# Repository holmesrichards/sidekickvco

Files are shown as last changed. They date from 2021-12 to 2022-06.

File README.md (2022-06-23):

# Sidekick VCO

The Sidekick VCO is a 3340 based voltage controlled oscillator synth module in Kosmo format. Notable features of the Sidekick include:

* Triangle, ramp, pulse, and sine waveforms with separate output jacks.
* Uniform, zero-centered ±5 Vpp output amplitudes for the various wave shapes.
* Input jacks for V/oct, PWM, and linear FM CV.
* Wide pulse width range.
* Switch selectable hard, soft, or no sync.
* 5 position octave switch plus fine tuning knob.
* Front panel access to trimmers for calibration of V/oct tracking, center pitch, and pulse width range limit.
* Entirely through hole construction with readily available components.

Two well known problems with the 3340 in its datasheet configuration are addressed:

* Regulated -5 V supply improves stability and suppresses pulse width frequency shift.
* Falling edge oscillations on pulse wave shape are eliminated.

But perhaps the most significant feature of the design is the link header. This may be used to connect the Sidekick's sister module, the [Hero VCO](https://github.com/holmesrichards/herovco), to one or more Sidekicks, in a modern riff on the classic Moog 921a/921b system. The Sidekick is half the width of the Hero and lacks some of the Hero's front panel controls and inputs, but internally is essentially the same circuit as the Hero. Via the link, the Sidekicks receive summed V/oct pitch CV, linear FM CV, and pulse width CV from the Hero, based on its front panel controls and inputs. In this way a common set of control voltages is presented to the Hero and all its Sidekicks. The link also permits the Sidekicks to be hard or soft synced to the Hero. This allows easy configuration of a multi-oscillator synth voice in a relatively compact system.

The Sidekick design specifies and assumes the Alfa AS3340A VCO chip, an improvement to the AS3340, although the AS3340 or Curtis CEM3340 probably would work. (See build notes.)

Thanks for inspiration to several other VCOs: the [Kassutronics VCO 3340](https://kassu2000.blogspot.com/2018/06/vco-3340.html), the [LMNC 1222 Performance VCO](https://www.lookmumnocomputer.com/1222-performance-vco), and the [Thomas Henry VCO Maximus](https://www.birthofasynth.com/Thomas_Henry/Pages/VCO_Maximus-Detail.html).

## Project status

One prototype has been built and it works. There were some very minor issues with the PCB which have been corrected in the design files but the revised version has not been built.

## Width

5 cm.

## Current draw
? mA +12 V, ? mA -12 V.

## Photos

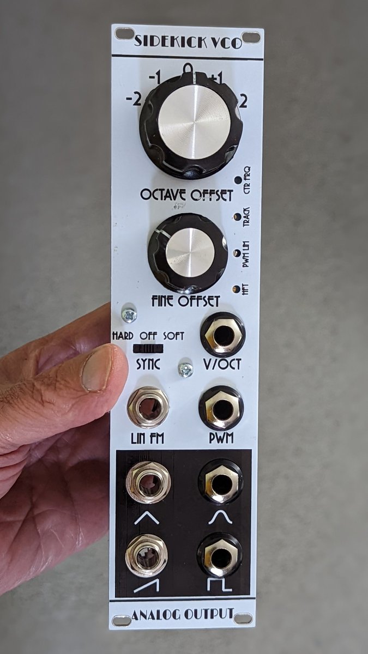
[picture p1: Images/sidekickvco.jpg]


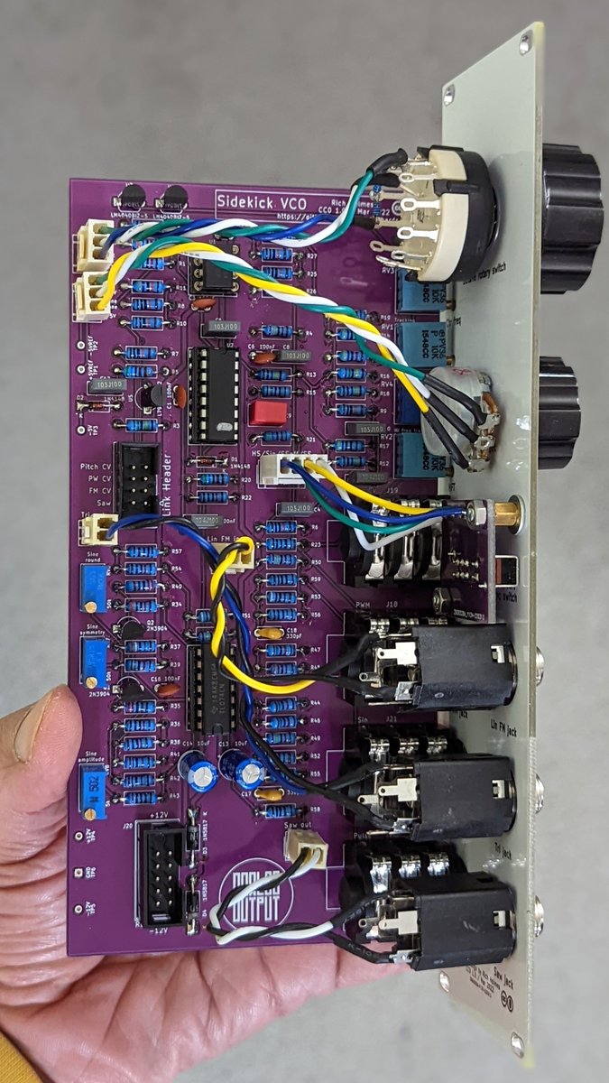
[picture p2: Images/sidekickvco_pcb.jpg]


## Documentation

* [Schematic](Docs/sidekickvco.pdf)
* PCB layout: [front](Docs/sidekickvco_layout_front.pdf), [back](Docs/sidekickvco_layout_back.pdf)
* [BOM](Docs/sidekickvco_bom.md)
* [Build notes](Docs/build.md)
* [How it works](Docs/howitworks.md)
* [Blog post](https://analogoutputblog.wordpress.com/2022/06/20/hero-and-sidekick/)

## GitHub repository

* [https://github.com/holmesrichards/sidekickvco](https://github.com/holmesrichards/sidekickvco)

## Submodules

This repo uses submodules aoKicad and Kosmo_panel, which provide needed libaries for KiCad. To clone:

```
git clone git@github.com:holmesrichards/sidekickvco.git
git submodule init
git submodule update
```

Alternatively do

```
git clone --recurse-submodules git@github.com:holmesrichards/sidekickvco.git
```

Or if you download the repository as a zip file, you must also click on the "aoKicad" and "Kosmo\_panel" links on the GitHub page (they'll have "@ something" after them) and download them as separate zip files which you can unzip into this repo's aoKicad and Kosmo\_panel directories.

If desired, copy the files from aoKicad and Kosmo\_panel to wherever you prefer (your KiCad user library directory, for instance, if you have one). Then in KiCad, go into Edit Symbols and add symbol libraries 

```
aoKicad/ao_symbols
Kosmo_panel/Kosmo
```
and go into Edit Footprints and add footprint libraries 
```
aoKicad/ao_tht
Kosmo_panel/Kosmo_panel.
```

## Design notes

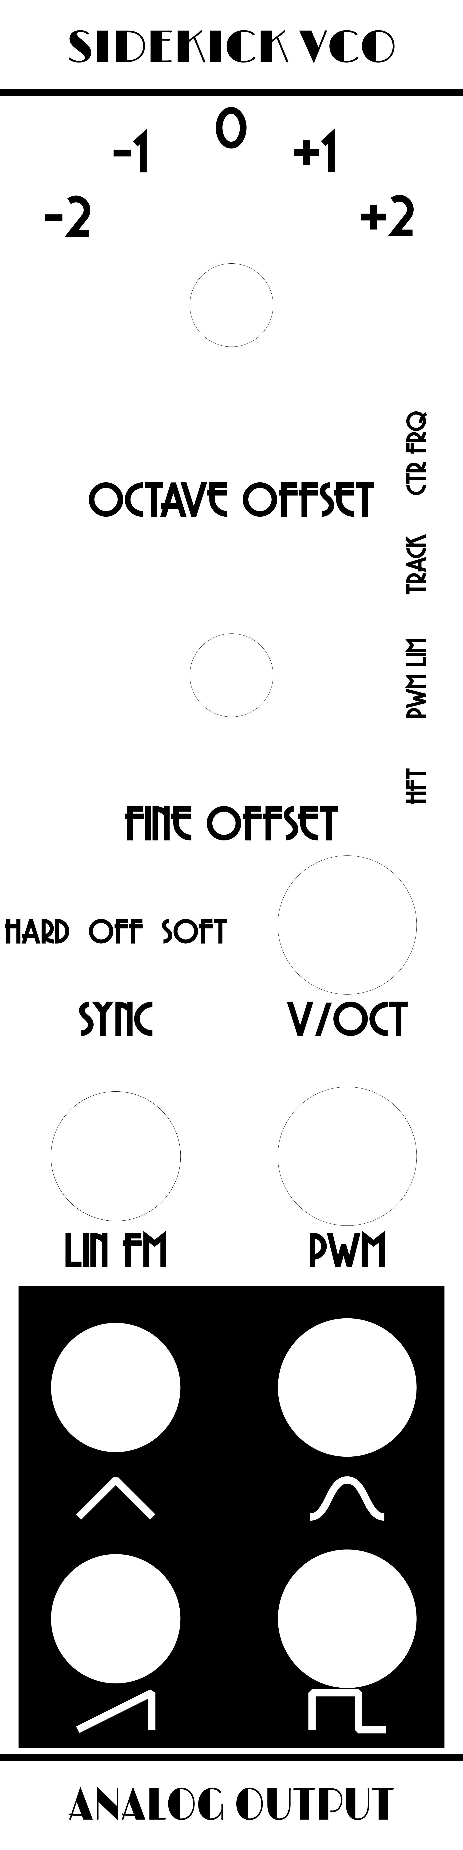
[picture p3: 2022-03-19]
Images/sidekick_panel_art.png

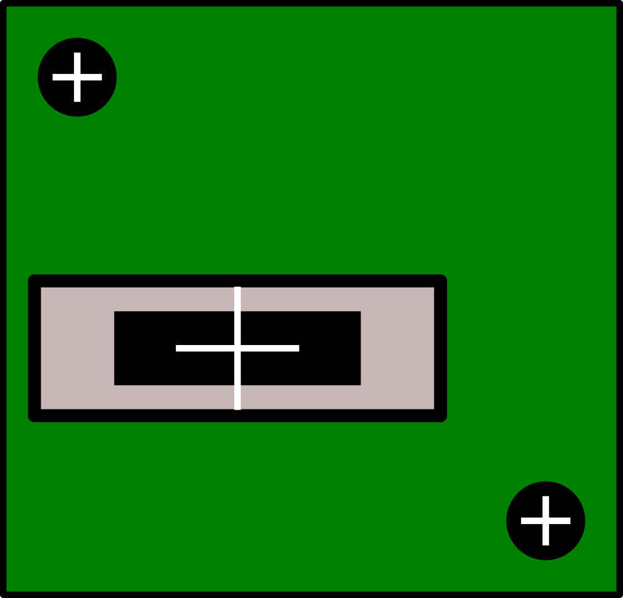
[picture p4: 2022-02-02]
Images/sidekick_daughterboard.png

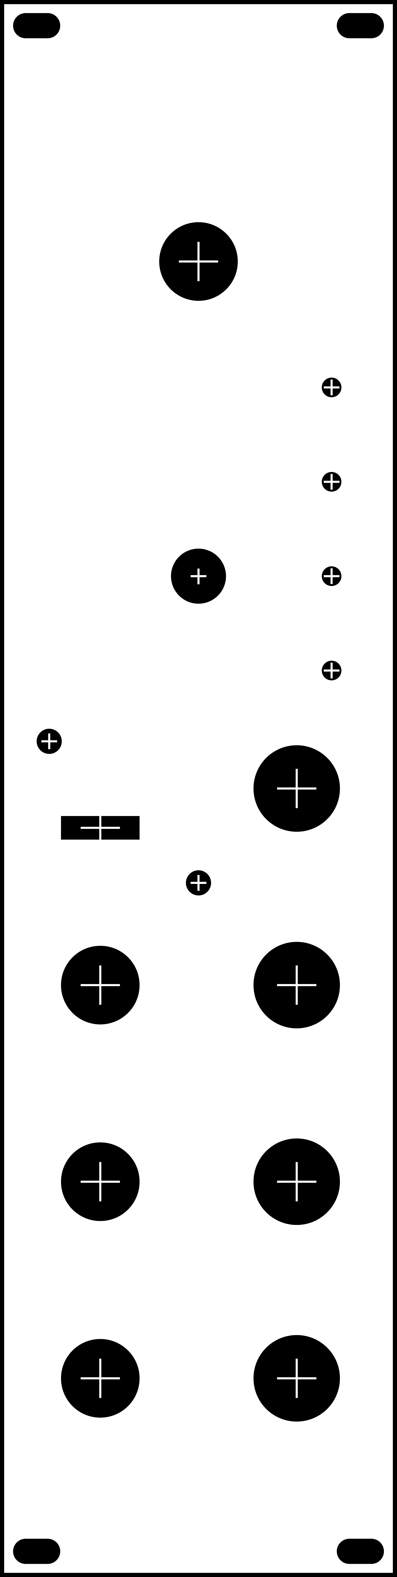
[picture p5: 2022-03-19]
Images/sidekick_panel_holes.png

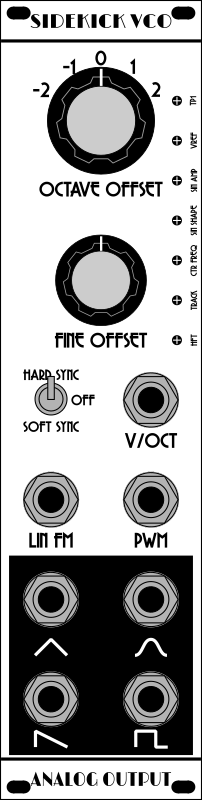
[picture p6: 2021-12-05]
Images/sidekick_panel.png

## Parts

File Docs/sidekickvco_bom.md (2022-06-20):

# sidekickvco.kicad_sch BOM

Sun 19 Jun 2022 12:23:22 PM EDT

Generated from schematic by Eeschema 6.0.5-a6ca702e91~116~ubuntu20.04.1

**Component Count:** 120

| Refs | Qty | Component | Description | Manufacturer | Part | Vendor | SKU |
| ----- | --- | ---- | --- | ---- | ---- | ---- | ---- |
| C1, C2, C3, C6, C15, C16 | 6 | 100nF | Ceramic capacitor, pitch 2.5 mm |  |  | Tayda |  |
| C4, C5, C8, C10, C12 | 5 | 10nF | Film capacitor, pitch 5 mm |  |  | Tayda | A-559 |
| C7, C11 | 2 | 100nF | Film capacitor, pitch 5 mm |  |  | Tayda | A-564 |
| C9 | 1 | 1nF | Polypropylene film capacitor |  |  | Digi-Key | FKP2G011001D00HSSD |
| C13, C14 | 2 | 10uF | Electrolytic capacitor, pitch 2.5 mm |  |  | Tayda |  |
| C17, C18 | 2 | 330pF | Ceramic capacitor, pitch 5 mm |  |  | Tayda |  |
| D1, D2 | 2 | 1N4148 | Standard switching diode, DO-35 |  |  | Tayda | A-157 |
| D3, D4 | 2 | 1N5817 | Schottky Barrier Rectifier Diode, DO-41 |  |  | Tayda | A-159 |
| J1 | 1 | Conn_02x04_Odd_Even | 2x4 shrouded pin header, pitch 2.54 mm |  |  | Tayda | A-2948 |
| J2, J3 | 2 | 3_pin_Molex_header | KK254 Molex header |  |  | Tayda | A-805 |
| J4 | 1 | 4_pin_Molex_header | KK254 Molex header |  |  | Tayda | A-806 |
| J5, J6, J7 | 3 | 2_pin_Molex_header | KK254 Molex header |  |  | Tayda | A-804 |
| J8, J9 | 2 | 3_pin_Molex_connector | KK254 Molex connector |  |  | Tayda | A-827 |
| J10 | 1 | 4_pin_Molex_connector | KK254 Molex connector |  |  | Tayda | A-828 |
| J11, J12, J13 | 3 | 2_pin_Molex_connector | KK254 Molex connector |  |  | Tayda | A-826 |
| J18, J19, J21, J22 | 4 | AudioJack2 | 1/4" audio jack, horizontal |  |  | Tayda | A-1122 |
| J20 | 1 | Synth_power_2x5 | 2x5 shrouded pin header, pitch 2.54 mm |  |  | Tayda | A-2939 |
| J23, J24, J25 | 3 | AudioJack2 | 1/4" audio jack, vertical |  |  | Tayda | A-1121 |
| Q1, Q2 | 2 | 2N3904 | Small Signal NPN Transistor, TO-92 |  |  | Tayda | A-111 |
| R1, R2, R34 | 3 | 30k | Resistor |  |  | Tayda |  |
| R3, R12, R13, R18 | 4 | 1M | Resistor |  |  | Tayda |  |
| R4, R48, R49, R50 | 4 | 24k | Resistor |  |  | Tayda |  |
| R5, R20 | 2 | 5.6k | Resistor |  |  | Tayda |  |
| R6, R7, R8, R9, R10, R25, R26, R27 | 8 | 100k | Resistor |  |  | Tayda |  |
| R11 | 1 | 470k | Resistor |  |  | Tayda |  |
| R14, R17 | 2 | 470R | Resistor |  |  | Tayda |  |
| R15 | 1 | 1.8k | Resistor |  |  | Tayda |  |
| R16 | 1 | 1.5M | Resistor |  |  | Tayda |  |
| R19, R21, R28 | 3 | 47k | Resistor |  |  | Tayda |  |
| R22, R36, R38, R54, R55, R56 | 6 | 10k | Resistor |  |  | Tayda |  |
| R23, R24, R57, R58, R59 | 5 | 1k | Resistor |  |  | Tayda |  |
| R29, R41, R42 | 3 | 20k | Resistor |  |  | Tayda |  |
| R30, R31, R32, R33 | 4 | 10k 1/8W | Resistor |  |  | Tayda |  |
| R35, R40 | 2 | 2.2k | Resistor |  |  | Tayda |  |
| R37 | 1 | 390R | Resistor |  |  | Tayda |  |
| R39, R44, R46, R47 | 4 | 18k | Resistor |  |  | Tayda |  |
| R43 | 1 | 2k | Resistor |  |  | Tayda |  |
| R45 | 1 | 33k | Resistor |  |  | Tayda |  |
| R51, R52, R53 | 3 | 9.1k | Resistor |  |  | Tayda |  |
| RV1, RV2, RV3 | 3 | 10k | 3296P trimmer potentiometer |  |  | Digi-Key | CT94EP103-ND |
| RV4 | 1 | 50k | 3296P trimmer potentiometer |  |  | Digi-Key | CT94EP503-ND |
| RV5 | 1 | 100k | Panel mount linear potentiometer |  |  | Tayda | A-5606 or A-1984 |
| RV6, RV7 | 2 | 50k | 3296W trimmer potentiometer |  |  | Tayda | A-598 |
| RV8 | 1 | 5k | 3296W trimmer potentiometer |  |  | Tayda | A-597 |
| SW1 | 1 | SW_Rotary12 | rotary switch with 12 positions |  |  | Tayda | A-1893 |
| SW2 | 1 | SW_DP3T | Switch, three position, dual pole triple throw, 3 position switch, SP3T | C&K | OS203012MU5QP1‎ | Digi-Key | CKN9554-ND |
| U1 | 1 | TL072 | Dual operational amplifier, DIP-8 |  |  | Tayda | A-037 |
| U2 | 1 | AS3340A | VCO |  |  | CabinTech Global |  |
| U3, U4 | 2 | LM4040BIZ-5 | 5.000V Precision Micropower Shunt Voltage Reference, TO-92 |  |  | Digi-Key | LM4040BIZ-5/NOPB-ND |
| U5 | 1 | L79L05_TO92 | Negative 100mA -30V Linear Regulator, Fixed Output -5V, TO-92 |  |  | Tayda | A-4676 |
| U6 | 1 | TL074 | Quad operational amplifier, DIP-14 |  |  | Tayda | A-1138 |
| | 2 or more* | | 8 pin IDC connector | | | Tayda | A-3346 |
| | Length as needed | | 8 conductor ribbon cable | | | Tayda | A-4935 |
| | 2 | | Knob | | | | |
| | 1 | | 8 pin DIP socket | | | Tayda | A-001 |
| | 1 | | 14 pin DIP socket | | | Tayda | A-004 |
| | 1 | | 16 pin DIP socket | | | Tayda | A-003 |
| | 2 | | M3x12 screw | | | | |
| | 2 | | 5 mm spacer | | | Tayda | A-1235 |
| | 2 | | M3 nut | | | | |
    
\* One connector for Hero and one for each Sidekick connecting to it

## Caveat emptor

Bourns 3296P 10k trimmers are specified for the panel accessible trimmers. Bourns PV36 trimmers seem to have the same specs and dimensions, as do Nidec Copal CT94E trimmers. Any of these should work. Similar trimmers from other manufacturers *may* differ slightly in their dimensions which may cause misalignment between panel and PCB. Compare datasheets carefully before buying.

The jacks are from Tayda, SKU A-1122 or A-3617 (seemingly identical). This appears to be the same as jacks sold under the model number PJ-644C elsewhere. Again, similar looking jacks from other sources may have slightly different dimensions.

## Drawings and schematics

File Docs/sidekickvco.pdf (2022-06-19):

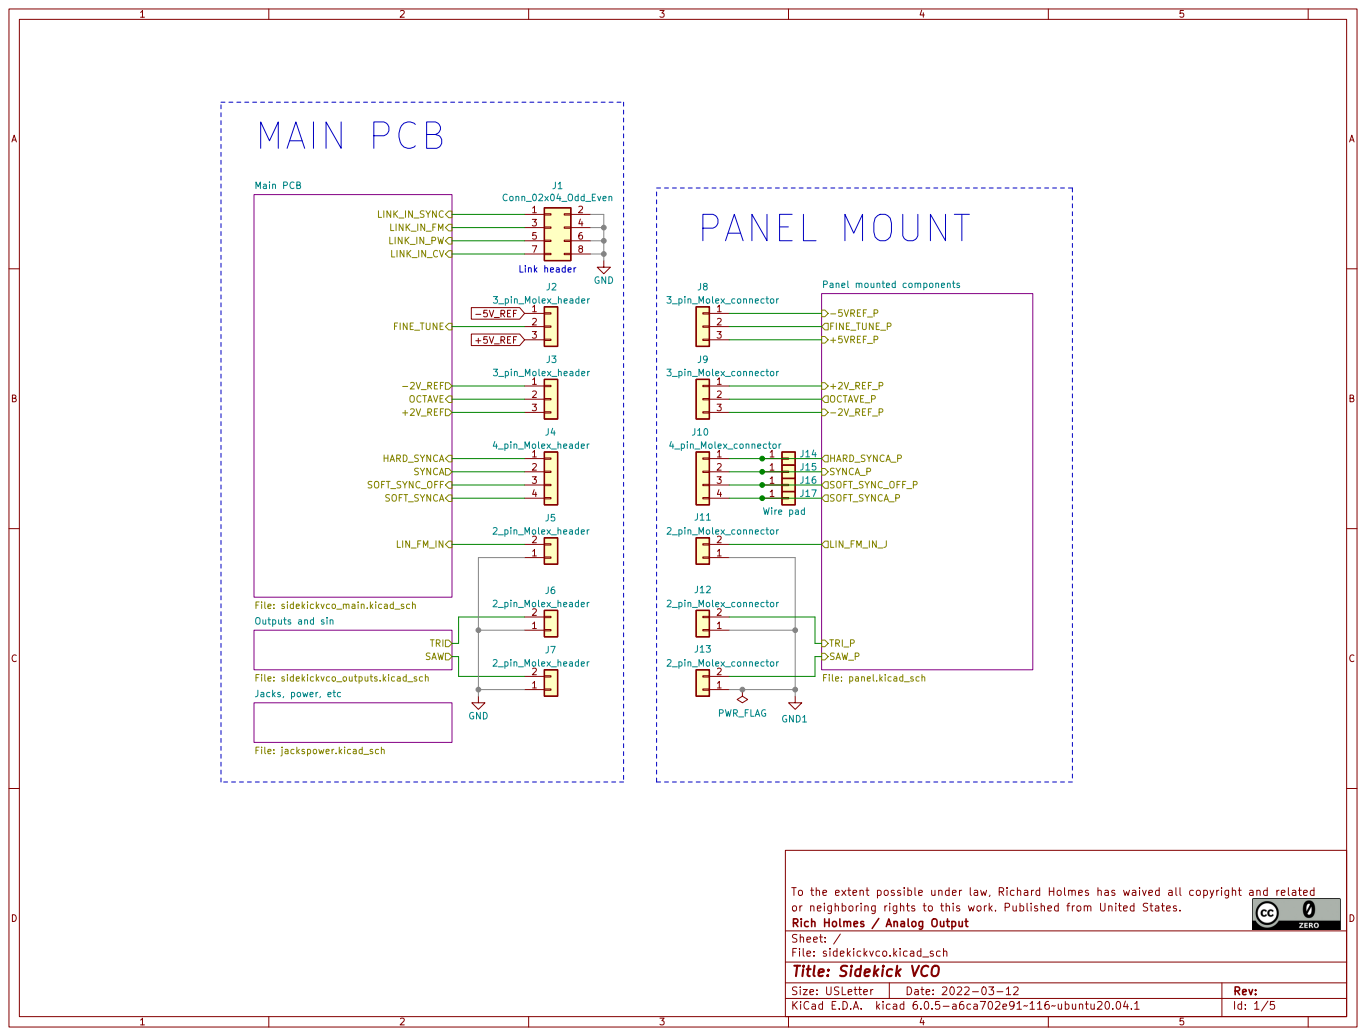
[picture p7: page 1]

+2V_REF_P
To the extent possible under law, Richard Holmes has waived all copyright and related OCTAVE_P

File: panel.kicad_sch TRI SAW

or neighboring rights to this work. Published from United States.
File: sidekickvco.kicad_sch Sheet: / Rich Holmes / Analog Output

Id: 1/5 Title: Sidekick VCO

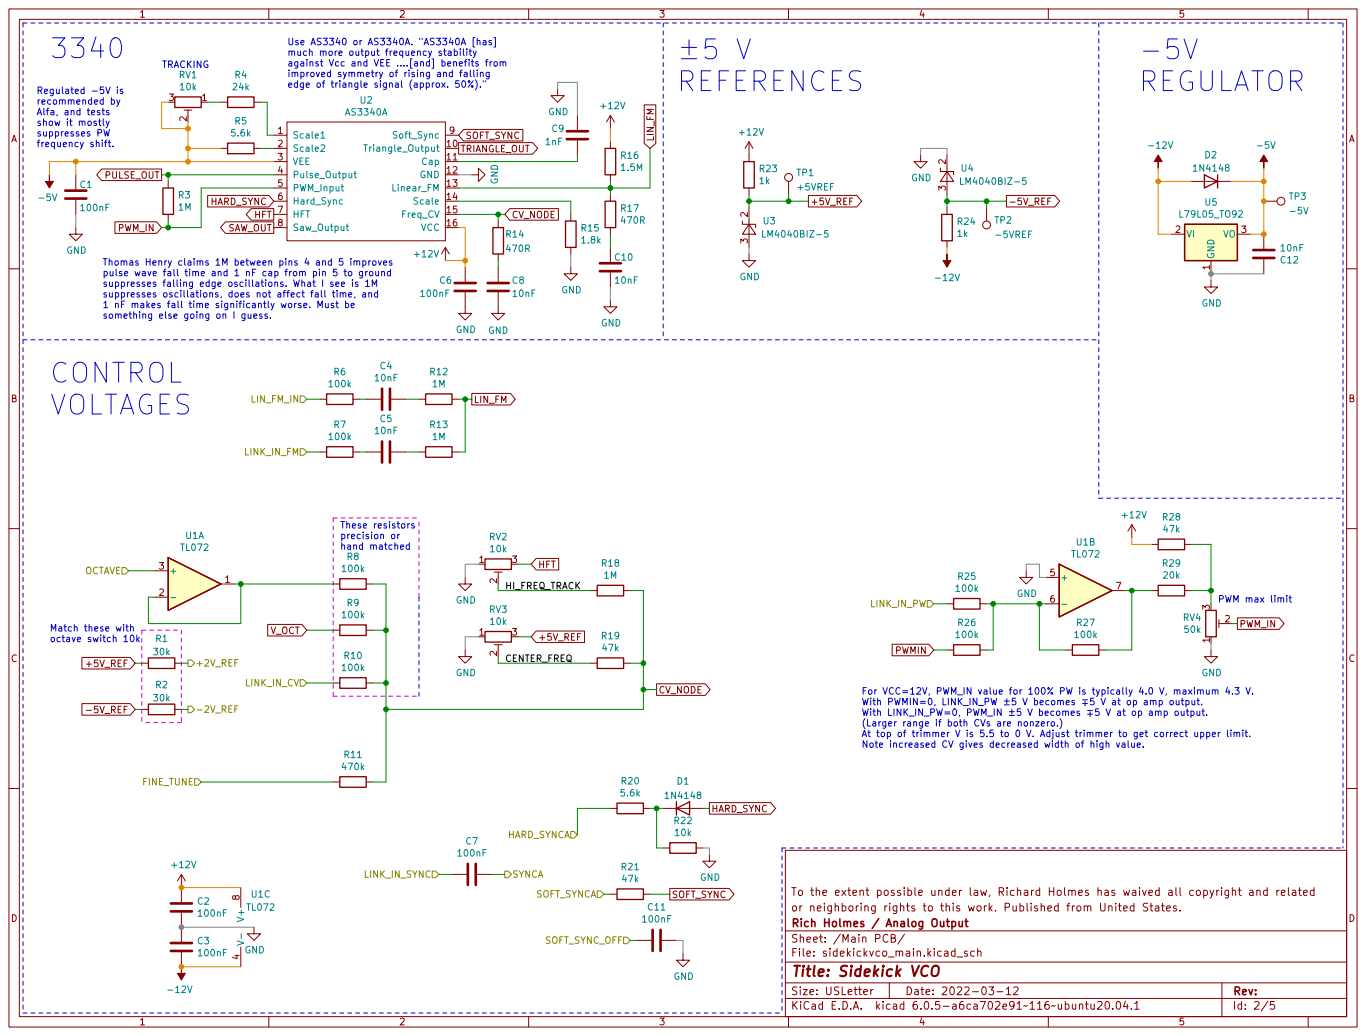
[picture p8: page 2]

Use AS3340 or AS3340A. "AS3340A [has]
much more output frequency stability
against Vcc and VEE ....[and] benefits from
improved symmetry of rising and falling
edge of triangle signal (approx. 50%)."

Regulated -5V is
recommended by Alfa, and tests

Thomas Henry claims 1M between pins 4 and 5 improves
pulse wave fall time and 1 nF cap from pin 5 to ground
suppresses falling edge oscillations. What I see is 1M
suppresses oscillations, does not affect fall time, and
1 nF makes fall time significantly worse. Must be

These resistors precision or hand matched

(Larger range if both CVs are nonzero.)
At top of trimmer V is 5.5 to 0 V. Adjust trimmer to get correct upper limit.
Note increased CV gives decreased width of high value.

To the extent possible under law, Richard Holmes has waived all copyright and related D1

or neighboring rights to this work. Published from United States.
File: sidekickvco_main.kicad_sch Sheet: /Main PCB/ Rich Holmes / Analog Output

Id: 2/5 Title: Sidekick VCO

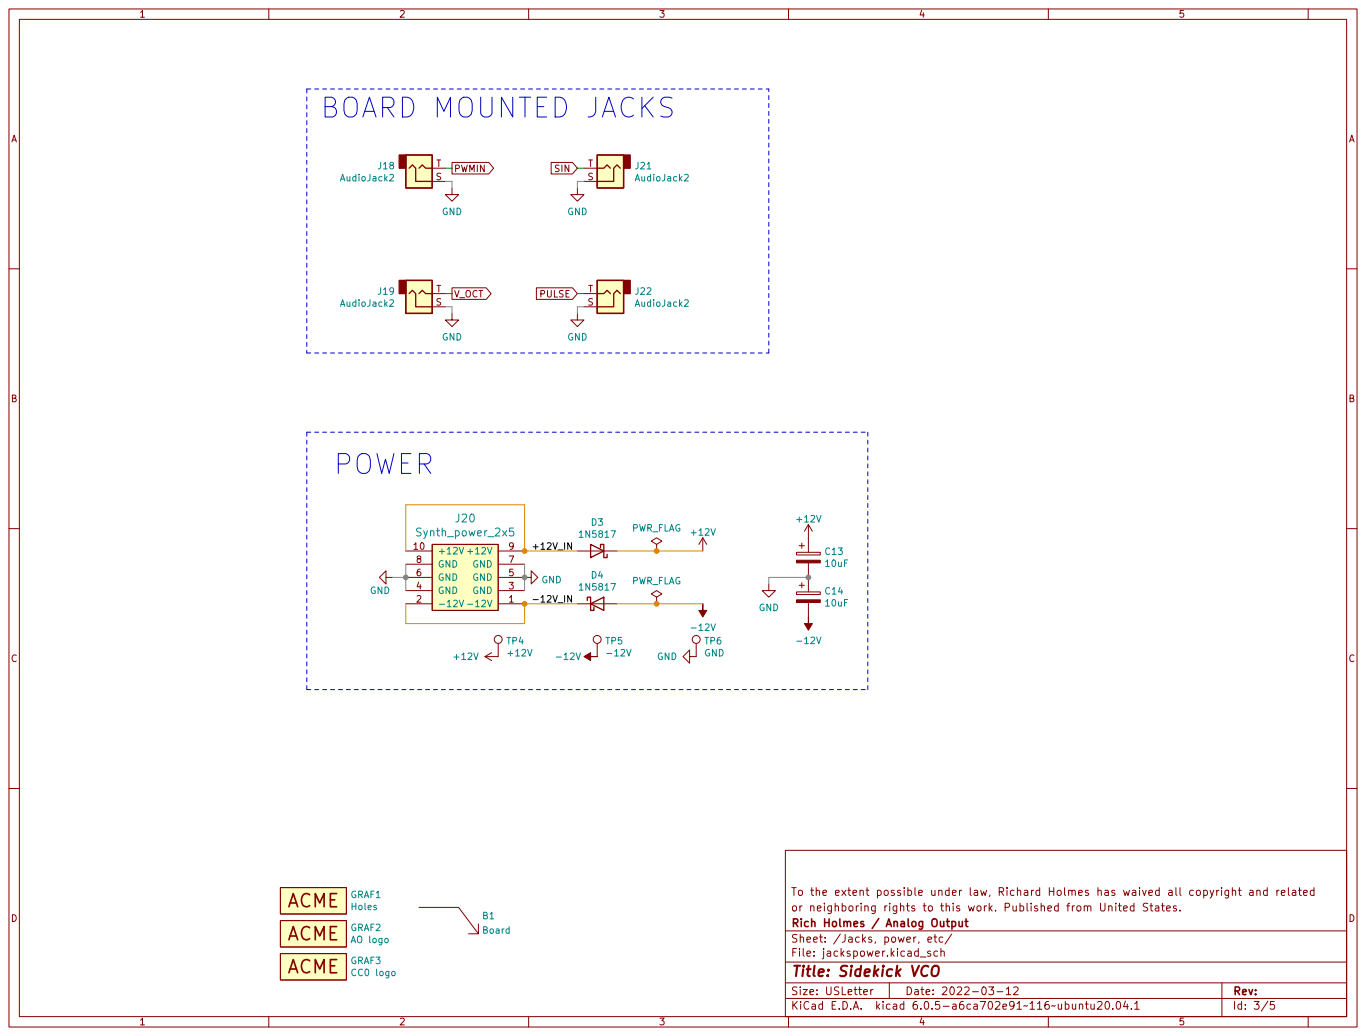
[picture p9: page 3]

To the extent possible under law, Richard Holmes has waived all copyright and related TP5

or neighboring rights to this work. Published from United States.
Rich Holmes / Analog Output
Sheet: /Jacks, power, etc/
File: jackspower.kicad_sch
Id: 3/5 Title: Sidekick VCO

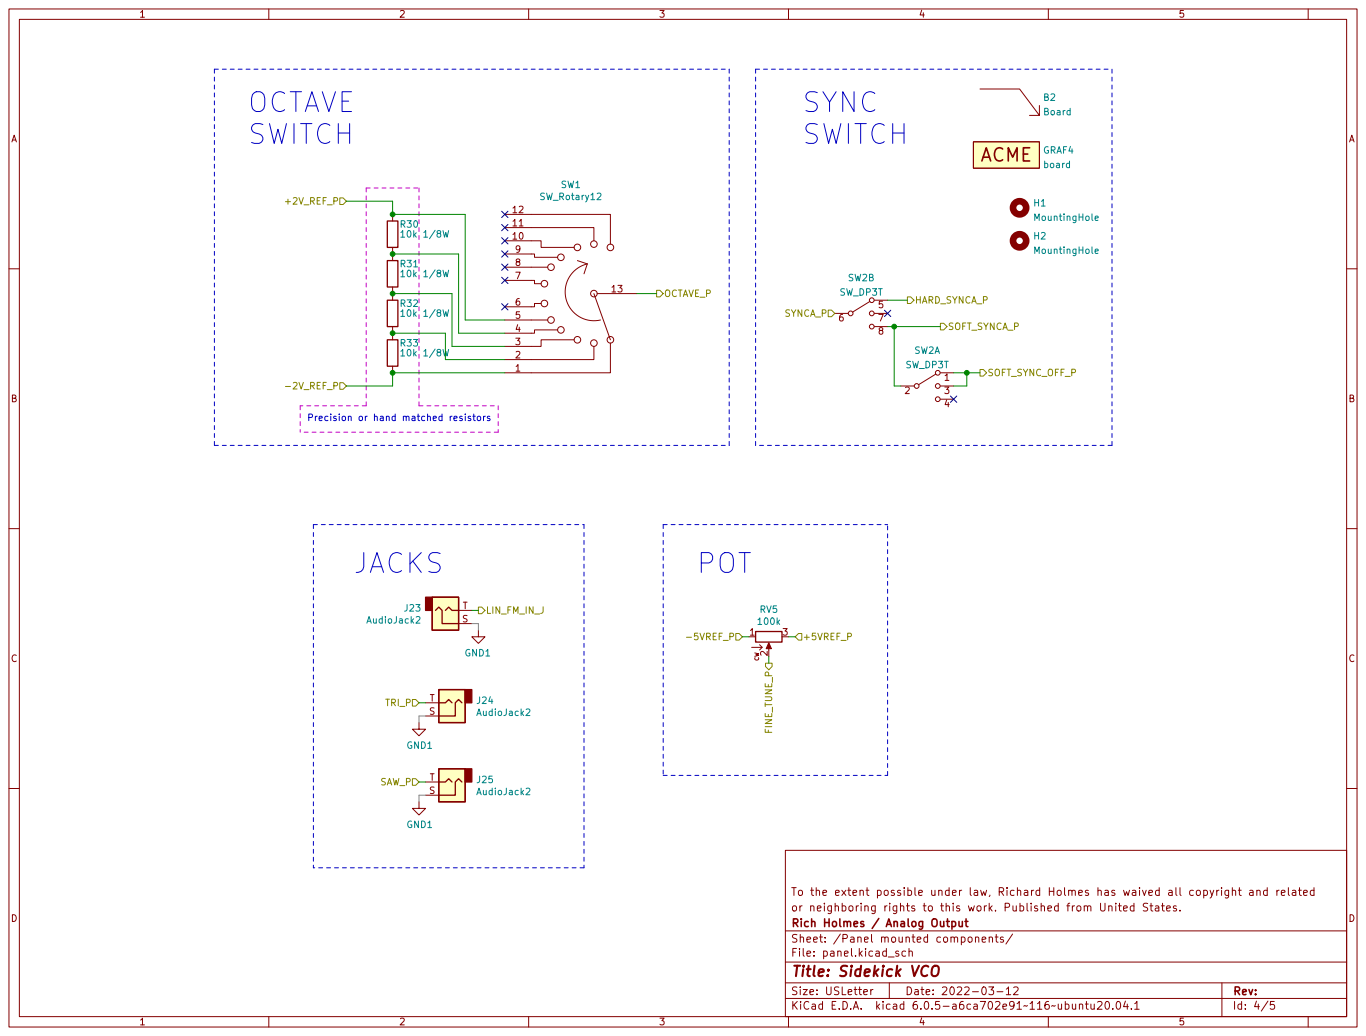
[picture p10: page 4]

To the extent possible under law, Richard Holmes has waived all copyright and related
or neighboring rights to this work. Published from United States.
Rich Holmes / Analog Output
Sheet: /Panel mounted components/
File: panel.kicad_sch
Id: 4/5 Title: Sidekick VCO

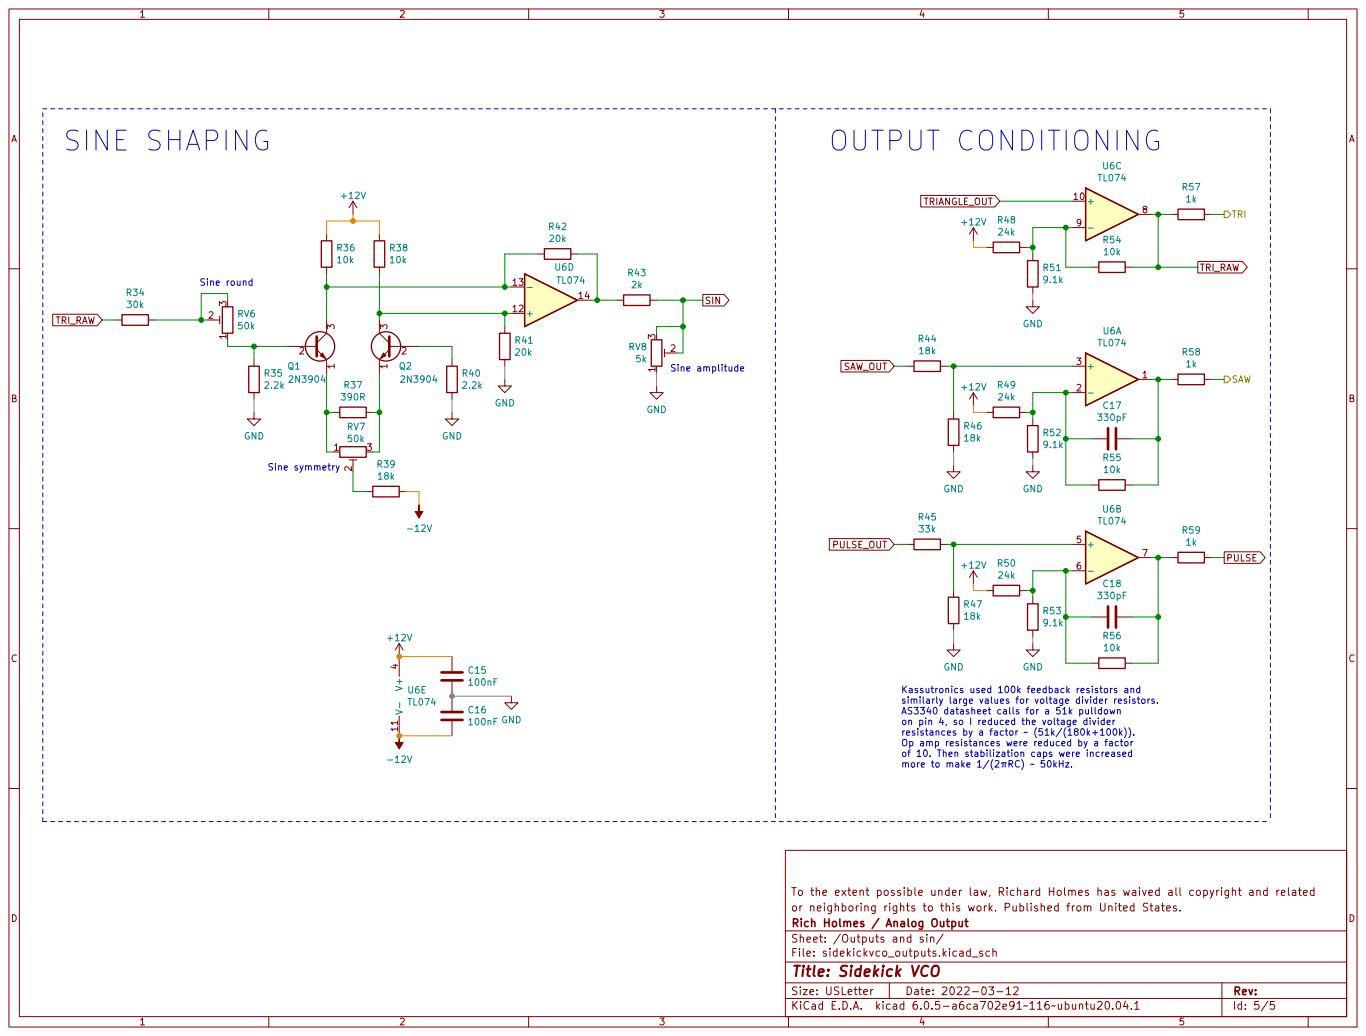
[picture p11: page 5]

To the extent possible under law, Richard Holmes has waived all copyright and related GND

Kassutronics used 100k feedback resistors and
similarly large values for voltage divider resistors.
AS3340 datasheet calls for a 51k pulldown
on pin 4, so I reduced the voltage divider
resistances by a factor ~ (51k/(180k+100k)).
Op amp resistances were reduced by a factor
of 10. Then stabilization caps were increased

or neighboring rights to this work. Published from United States.
Rich Holmes / Analog Output
Sheet: /Outputs and sin/
File: sidekickvco_outputs.kicad_sch
Id: 5/5 Title: Sidekick VCO

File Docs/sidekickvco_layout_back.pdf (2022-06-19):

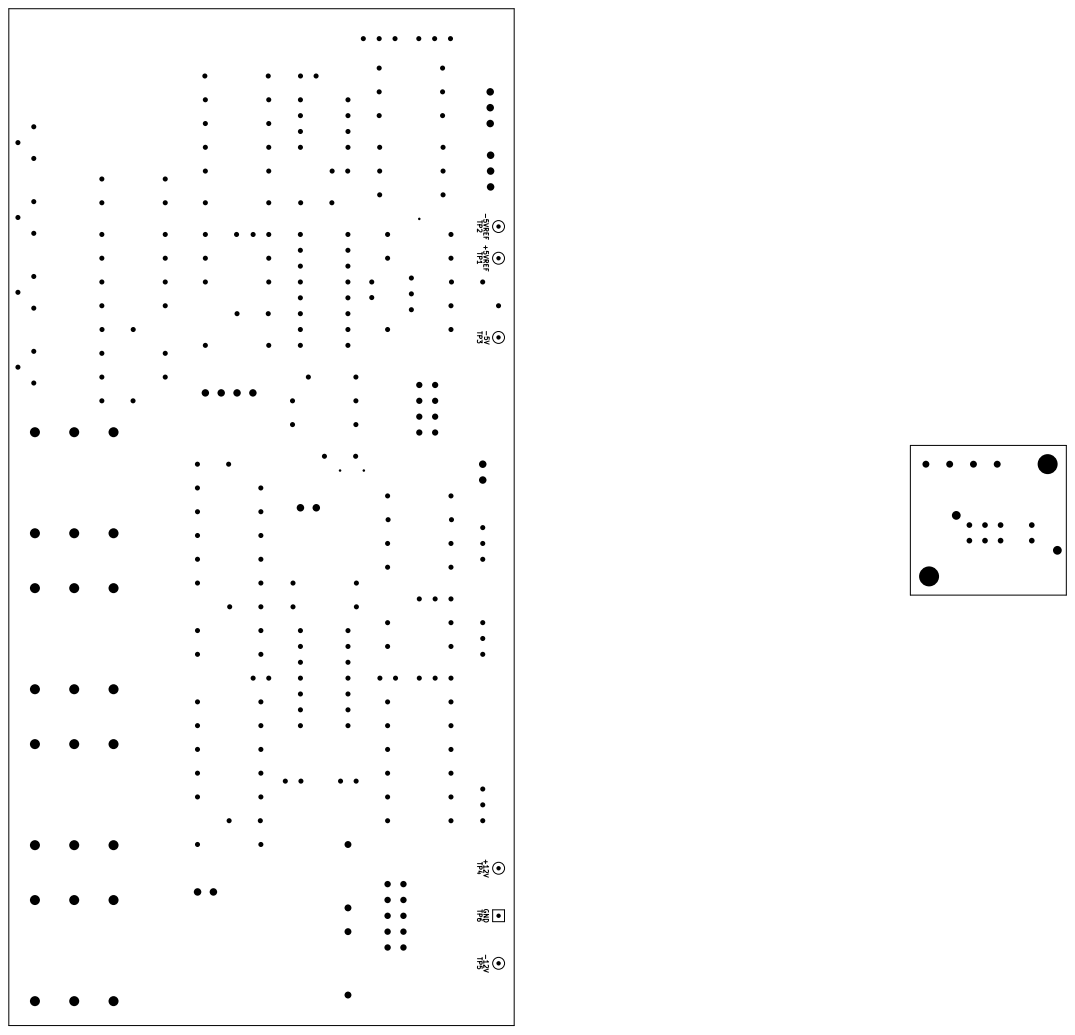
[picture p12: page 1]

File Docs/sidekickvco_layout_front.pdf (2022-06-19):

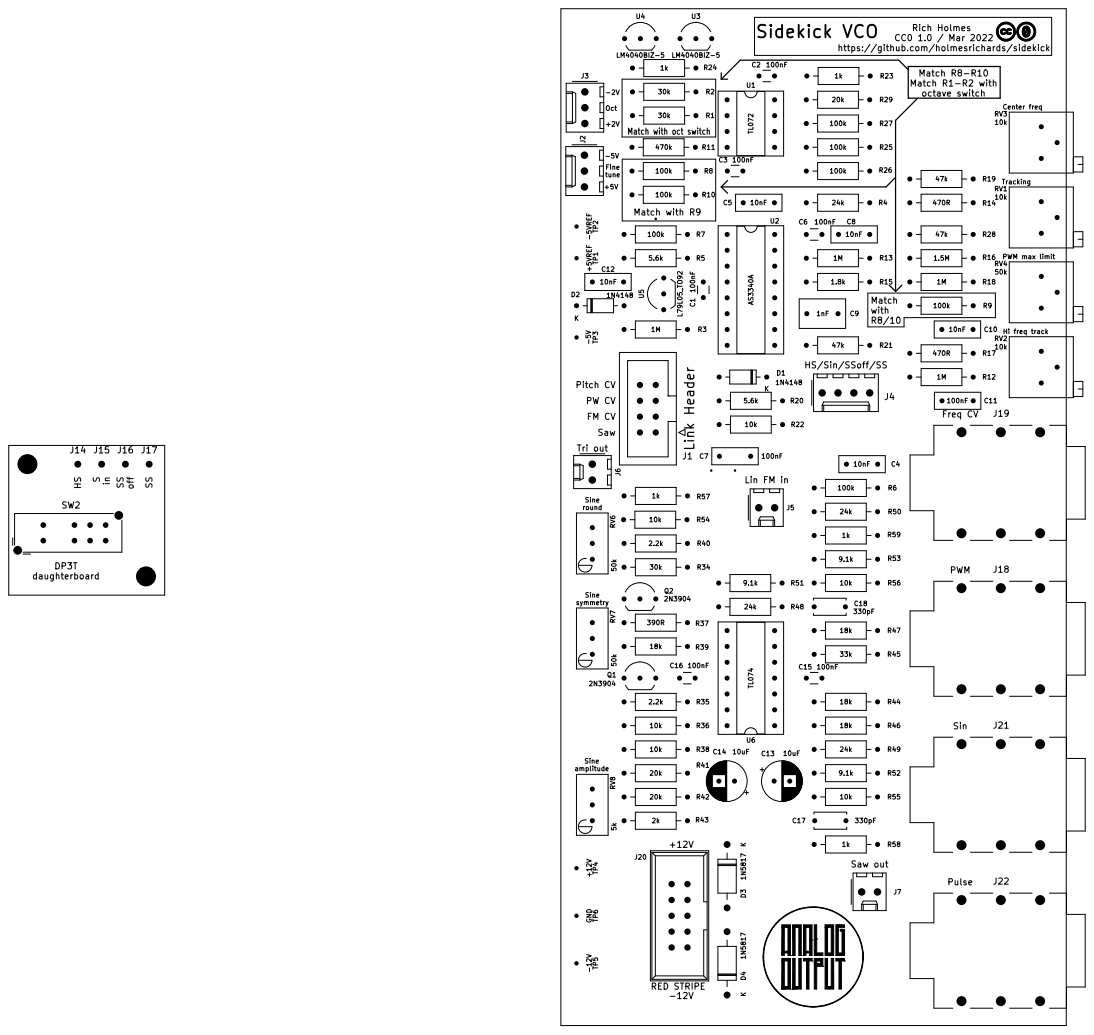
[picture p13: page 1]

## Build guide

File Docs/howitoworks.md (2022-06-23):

# How the Sidekick VCO works

## Control voltages

The linear FM control voltage from the front panel jack is AC coupled by C4, then R12 converts the voltage to current. The FM CV from the link header is handled the same way. The summed current is input to the 3340 chip.

The octave switch voltage output is buffered by U1A. RV5 supplies an adjustable offset voltage for fine tuning. RV2 attenuates the high frequency tracking voltage from the 3340, and RV3 creates an adjustable offset voltage to set the center frequency. All these voltages go to summing resistors and from there to the 3340 CV node. To make sure the octave switch and V/oct CVs remain accurately 1 V/oct the summing resistors must be matched.

The sync input is sent via switch SW2 to either the hard or soft sync circuit, or neither. For hard sync the level is divided by R20 and R22, the pulse width is set by those in combination with C7, and D1 causes only negative going pulses to be sent. For soft sync, R21 combined with C7 establishes the pulse width. If neither is selected, C11 is connected to the soft sync pin as recommended in the 3340 datasheet.

The pulse width modulation CVs from the front panel jack and the link header are summed and inverted by R25, R26, R27, and U1B. R28, R29, and RV4 scale and offset the resulting voltage to correspond to the 3340's PWM range (about 0 to 4 V with 12 V supply).

## 3340

The 3340 connections are mostly as in the datasheet. VEE is connected directly to -5 V, rather than via a resistor to -12 V, to improve performance and eliminate the pulse width frequency shift. R3 between pins 4 and 5 eliminates ringing oscillations on the falling edge of the pulse waveform.

## ±5 V references

Two LM4040 shunt voltage references, U4 and U5, are used with current limiting resistors R23 and R24 to create accurate ±5 V references, used by the fine tune control, center frequency trimmer, and octave switch.

## -5 V regulator

U5 is a voltage regulator to supply negative power to the 3340. D2 and C12 are per the L79L05 datasheet.

## Octave switch

Matched 10k resistors along with 30k resistors R1 and R2 form a precision voltage divider between ±5 V whose output is +2, +1, 0, -1, -2 V.

## Output conditioning

The 3340's waveform outputs are about 0 to 10.5 V for pulse, 0 to 8 V for ramp/saw, and 0 to 4 V for triangle. The triangle waveform is rescaled and offset to ±5 V by R48, R51, R54, and U6C. R48 and R51 divide +12 V down to the desired offset and the ratio of R54 to these resistors sets the gain. R57 limits current to the waveform output jack.

The same rescaling and offset circuit is used on the ramp and pulse waveforms as well, after a voltage divider (R44 and R46 for ramp, R45 and R47 for pulse) scales these outputs down to 0 to 4 V. R45 and R47 also serve as a 51k pulldown as called for in the AS3340 datasheet.

Using the +12 V rail for the offset means it is sensitive to power supply fluctuations, but this is not likely to be a concern.

## Sine shaping

The sine shaping circuit is based on a differential transistor pair, Q1 and Q2. This is a standard tri to sine design. The amount of rounding depends on the input signal level so attenuator RV6 gives control over that. RV7 adjusts the balance between the two transistors' bias to control the symmetry of the rounding. U6D with R41 and R42 is a differential current amplifier, turning the difference in the collector currents into an output voltage. R43 and RV8 attenuate the output down to ±5 V.

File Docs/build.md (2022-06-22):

# Sidekick VCO build notes

## Which chip

The design specifies and assumes the Alfa AS3340A VCO chip, an improvement to the AS3340, although the AS3340 or Curtis CEM3340 probably would work. I have not tested either extensively. The CEM datasheet says the pulse output should have a 10k pulldown, versus 51k for the AS3340(A), though reportedly anything in that range works acceptably for either (see Sam Battle's LMNC 1222 schematic). If using CEM and you want to stick to the datasheet you could try changing R45 from 33k to 6.2k and R47 from 18k to 3.6k.

## Resistor matching

For proper V/oct tuning, certain groups of resistors need to be matched to one another to high precision. You can buy 0.1% precision resistors, but it is much cheaper to buy 100 or so 1% resistors and then measure them, setting aside ones that match at the 0.1% level. The actual value of the resistance is not critical, only that it be the same for resistors in each group. Different groups do not need to match each other.

Resistor groups to be matched are:

* Summing resistors in pitch CV input stage: R8, R9, and R10 (100k). 
* Octave switch resistors: R30 through R33 (10k) and R1, R2 (30k). For the latter choose resistors equal to three times the former, within 0.1%.

*It would not hurt to make a note of the resistance values for each group.* You will want to know this if you ever need to replace one of these resistors.

## Octave switch

Resistors R30 through R33 are not mounted on the PCB; they are soldered directly to the octave switch: R33 from pin 1 to pin 2, R32 from pin 2 to pin 3, R31 from pin 3 to pin 4, and R30 from pin 4 to pin 5. (Nothing is connected to pins 6–12.) These resistors are specified as 1/8 W metal film, solely because they fit nicely between the switch pins. You can use 1/4 watt resistors if that is what you have. They're just more awkward to place.

Three wires are connected to a Molex connector, to attach to header J3 on the circuit board. The wire connecting to the header pin marked +2V connects to rotary switch pin 5. The wire to header pin -2V connects to pin 1. The wire to header pin Octave connects to the center pin.

### Slide switch daughterboard

This daughterboard is secured to the front panel with two each M3x12 screws, 5mm spacers, and M3 nuts. Solder stranded wires to the four pads provided and connect the other ends to the main PCB with a 4 position Molex connector (or solder directly).

## Calibration
The main calibration is the usual procedure with 3340 based oscillators:

* With the octave swich in position -2 adjust the Center freq trimmer to get a fairly low frequency (100 Hz or so)
* Use a calibrated V/oct source such as a CV keyboard or MIDI/CV module to send 0 V and 2 V alternately to the V/oct input. Adjust the Tracking trimmer until the frequency ratio at these two CV values equals 2.000 ± 0.002.
* Turn the octave switch up to position 2. Again alternating 0 V and 2 V on the V/oct input, adjust the Hi freq track trimmer until the frequency ratio at these two CV values equals 2.000 ± 0.002.
* Repeat the last two steps if necessary to get the tracking as accurate as you can.
* Re-adjust the center frequency trimmer to your liking. I recommend setting it so with the fine tune knob centered and the octave switch at the 0 position, it gives the same pitch as the controlling Hero VCO.

(I did the calibration using my new MI Module Tester and it made it so easy it was ridiculous!)

There are still four more trimmers! One is for the PWM upper limit. With no PWM CV, adjust it so when you turn the Pulse width knob up the pulse waveform either never gets so wide it stops, or gets just barely to the stopping point, as you prefer.

The other three trimmers are for the sine waveform. Put the sine waveform on a scope and adjust Sine symmetry to make the top and bottom of the waveform the same; adjust Sine round to make it a good sine shape. Once you're happy with those, adjust Sine amplitude to make the waveform 10 V peak to peak.

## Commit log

2022-01-30 Notes, first schem version
    [herovco_back.kicad_pcb, herovco_front.kicad_pcb, herovco_switch.kicad_pcb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]
2022-02-01 Initial version of circuit and layout
    [jackspower.kicad_sch, panel.kicad_sch, sidekickvco.kicad_pcb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]
2022-02-02 Daughterboard mounting
    [panel.kicad_sch, sidekickvco.kicad_pcb, sidekickvco.kicad_sch]
2022-02-04 Revise layout, add notes, BUILD.md
    [jackspower.kicad_sch, panel.kicad_sch, sidekickvco.kicad_pcb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]
2022-03-06 Correct slide switch footprint; use TO-92 wide for regulator
    [panel.kicad_sch, sidekickvco.kicad_pcb, sidekickvco.kicad_sch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]
2022-03-06 5 mm pitch for 330 pF
    [sidekickvco.kicad_pcb, sidekickvco.kicad_sch, sidekickvco_outputs.kicad_sch]
2022-03-09 Note on PW CV
    [sidekickvco_main.kicad_sch]
2022-03-09 Revised layout
    [sidekickvco.kicad_pcb, sidekickvco.kicad_sch]
2022-03-19 Pre prototype revisions, README revision
    [herovco_back.kicad_pcb, herovco_front.kicad_pcb, herovco_switch.kicad_pcb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]
2022-03-25 Fix nuked footprints; update trimmer footprints
    [jackspower.kicad_sch, panel.kicad_sch, sidekickvco.kicad_pcb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]
2022-06-13 Matching notes on silk
    [sidekickvco.kicad_pcb]
2022-06-14 Enlarge horizontal jack hole
    [sidekick_panel.kicad_pcb]
2022-06-14 Less ridiculous routing
    [sidekickvco.kicad_pcb]
2022-06-14 More routing tweaks
    [sidekickvco.kicad_pcb]
2022-06-14 Adjust trimmer footprints
    [sidekickvco.kicad_pcb]
2022-06-19 Post prototype updates
    [jackspower.kicad_sch, panel.kicad_sch, sidekickvco.kicad_sch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]
2022-06-20 Add link cable components to BOM
2022-06-20 kicad_pro updated itself
2022-06-20 new panel gerbers
    [sidekick_panel-CmtUser.gbr, sidekick_panel-CuBottom.gbl, sidekick_panel-CuTop.gtl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]
2022-06-23 Fix lin FM input, add howitworks
    [sidekickvco.kicad_pcb, sidekickvco.kicad_sch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]
2022-06-23 Restore resistor
    [sidekickvco.kicad_pcb, sidekickvco.kicad_sch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]
2022-07-08 New b1 Gerbers
    [sidekickvco_b1-CmtUser.gbr, sidekickvco_b1-CuBottom.gbl, sidekickvco_b1-CuTop.gtl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]
